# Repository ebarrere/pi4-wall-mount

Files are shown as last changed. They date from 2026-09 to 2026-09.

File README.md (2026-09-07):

# Raspberry Pi hanger

Use this to mount a Raspberry Pi 4 horizontally on the wall, assuming the Pi is mounted in [this case](https://www.printables.com/model/1240756-raspberry-pi-4-case-updated/files).

The mounting holes are sized and tapered for wood screws, but positioned to accomodate [Multiboard](https://thangs.com/designer/Keep%2520Making/3d-model/9x9%2520Multiboard%2520Core%2520Tile-977730).

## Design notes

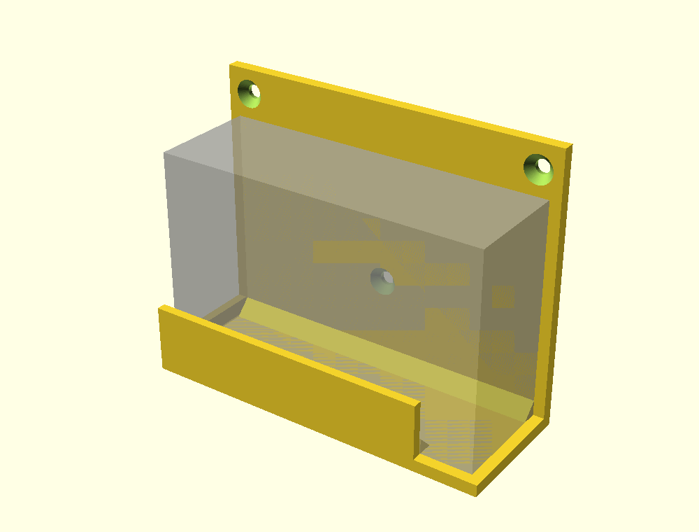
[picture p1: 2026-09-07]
pi4-wall-mount_iso.png

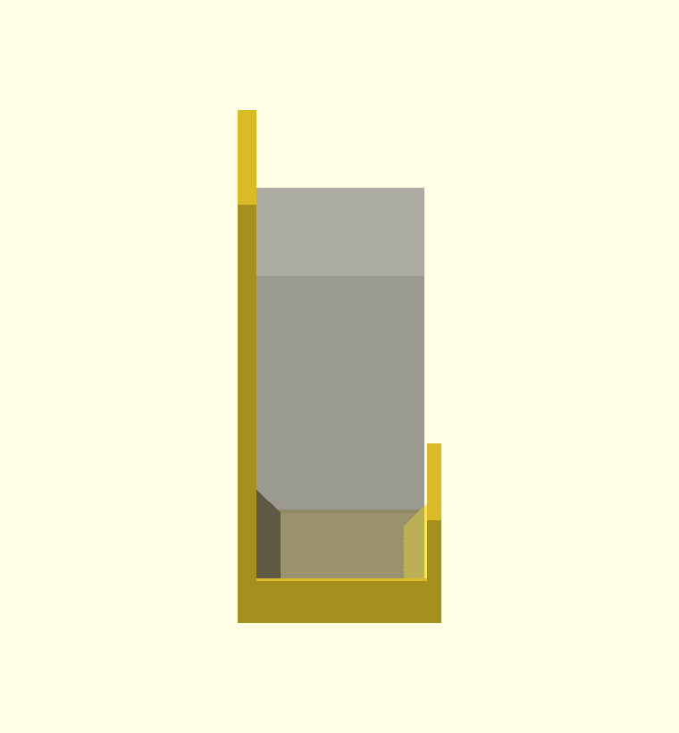
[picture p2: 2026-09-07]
pi4-wall-mount_side.png

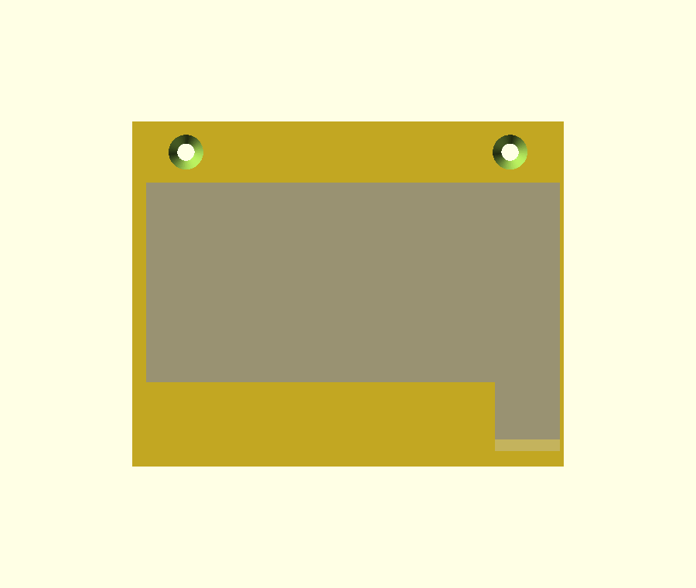
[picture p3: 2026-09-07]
pi4-wall-mount_front.png

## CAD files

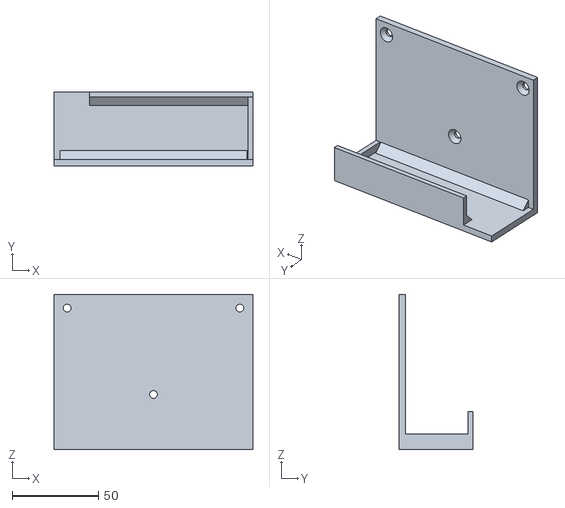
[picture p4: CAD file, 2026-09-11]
pi4-wall-mount.stl
115.2 x 43.1 x 90.0

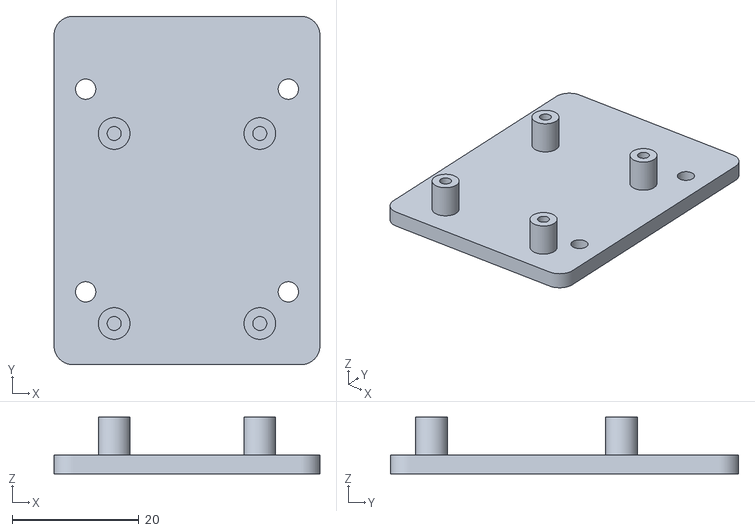
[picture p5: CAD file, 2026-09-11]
c790-pi-mount.stl
42.0 x 55.0 x 9.00

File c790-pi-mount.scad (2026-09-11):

// ============================================================================
// C790 (HDMI-to-CSI-2 capture, 30 x 45 mm PCB) -> Pi-case mounting tray
// Bolts to the case's 20 mm hole grid; stands the C790 off on 4 posts.
// Units: mm. Print flat (base on bed, posts up) -- no supports.
// ============================================================================

/* ========================= PARAMETERS ========================= */

// ---- C790 board ----
c790_w = 30;              // PCB width  (X)
c790_l = 45;              // PCB length (Y)
// Measured mounting-hole pattern (center-to-center). Board holes are 2.6 mm (M2.5).
c790_hole_dx = 23;        // hole spacing across the 30 mm WIDTH  (X)
c790_hole_dy = 30;        // hole spacing along  the 45 mm LENGTH (Y)
standoff_h   = 6;         // how high to lift the board off the base
standoff_od  = 5;         // post outer diameter (keeps clear of the fan holes)
board_screw_d = 2.2;      // hole in each post: 2.2 = self-tap M2.5; 2.7 = clearance for through-screw + nut
post_setback = 6;         // shift the posts (and board) toward a short edge (-Y); centered on the long edge. Flip sign for the other short edge.

// ---- Mount to the case-top FAN screw holes (4 holes in a square) ----
fan_pitch    = 32;        // fan hole spacing, on-center (40 mm fan = 32 mm; measure to confirm)
fan_screw_d  = 3.2;       // clearance for the fan screws (~M3)

// ---- Base plate ----
base_th     = 3;          // plate thickness
base_margin = 5;          // material around the widest feature
corner_r    = 3;          // corner radius
show_board_ghost = true;  // translucent PCB outline for visual check (not printed)

$fn = 64;
/* ============================================================== */


/* ------- derived geometry ------- */
hx = c790_hole_dx/2;                    // C790 hole X offset from center
hy = c790_hole_dy/2;                    // C790 hole Y offset from center
c790_holes = [[hx,hy],[-hx,hy],[hx,-hy],[-hx,-hy]];

// posts sit setback toward a short edge (-Y); no X offset keeps them centered on the long edge
post_holes = [ for (p = c790_holes) [p[0], p[1] - post_setback] ];

// fan mount holes: 4 in a square at fan_pitch on-center
fan_holes = [ for (sx=[-1,1], sy=[-1,1]) [sx*fan_pitch/2, sy*fan_pitch/2] ];

base_w = max(c790_w, fan_pitch) + 2*base_margin;
base_l = max(c790_l, fan_pitch) + 2*base_margin;


/* ------- helper modules ------- */
module rounded_square(w, l, r) {
    hull() for (sx=[-1,1], sy=[-1,1])
        translate([sx*(w/2-r), sy*(l/2-r)]) circle(r=r);
}


/* ------- the part ------- */
module tray() {
    difference() {
        union() {
            // base plate
            linear_extrude(base_th) rounded_square(base_w, base_l, corner_r);
            // C790 standoffs
            for (p = post_holes)
                translate([p[0], p[1], 0])
                    cylinder(d=standoff_od, h=base_th + standoff_h);
        }
        // fan-mount holes (through the base)
        for (p = fan_holes) translate([p[0], p[1], -0.5])
            cylinder(d=fan_screw_d, h=base_th + 1);
        // board screw holes (top-down into each post only)
        for (p = post_holes)
            translate([p[0], p[1], base_th])
                cylinder(d=board_screw_d, h=standoff_h + 1);
    }
}

tray();

// translucent ghost of the C790 sitting on the posts (visual only)
if (show_board_ghost)
    %translate([0, -post_setback, base_th + standoff_h])
        linear_extrude(1.2) square([c790_w, c790_l], center=true);

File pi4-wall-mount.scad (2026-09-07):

// ============================================================================
// Raspberry Pi 4 case -> wall-mount cradle (ikea-type shelf side wall)
// Mounted pose: case flat against the wall, power/HDMI edge UP. Held by a floor
// + short front lip + a side lip along the USB/Ethernet edge. Back plate screws
// to the shelf board (countersunk). Inside 45-deg fillets mate the case's
// bottom chamfers.
//
// Coords: X = horizontal (along wall), Y = out from wall, Z = up. Units: mm.
// The USB/Ethernet ("back") edge is the +X side; the case protrusion is on the
// far (-X) side, so the front lip is offset toward +X to clear it.
// Set usb_on_right=false to mirror everything to the other hand.
// ============================================================================

/* ===== CASE (measured, assembled, as mounted) ===== */
case_w = 108;    // horizontal width against the wall
case_h = 70;     // vertical height
case_d = 35.5;   // depth out from the wall
case_chamfer = 5;// case's 45-deg bottom-edge chamfer (measured); drives inside fillets
fit    = 0.6;    // clearance around the case

/* ===== BACK PLATE ===== */
plate_th   = 4;
top_margin = 16;   // strip above the case (top screws)

/* ===== CRADLE ===== */
floor_th     = 4;
front_lip_th = 3;
front_lip_h  = 18;
front_lip_w  = 91;   // < case_w, offset toward +X to clear the far-side protrusion
side_lip_th  = 3;    // lip along the USB/Ethernet (+X) edge
side_lip_h   = 5;    // its height above the floor

/* ===== WOOD SCREWS (countersunk; 1" #8) ===== */
screw_shank_d = 4.5;
head_d        = 9.0;
cs_angle      = 82;
// Hole layout on a 25mm lattice so it drops onto Multiboard (25mm tile pitch):
// two top holes 100mm apart, one low-center hole 50mm below -> all spacings x25.
screw_grid    = 25;
screw_top_x   = 50;    // top pair at +/- this (must be a multiple of screw_grid)
screw_low_dz  = 50;    // low-center hole this far below the top row (multiple of grid)

usb_on_right   = true;   // false = mirror to the other hand
show_case_ghost = true;
$fn = 64;

/* ===== derived ===== */
yc0 = plate_th;                 // case back (flush on plate)
yc1 = yc0 + case_d;             // case front
yfl0 = yc1 + fit;               // front lip inner
yfl1 = yfl0 + front_lip_th;     // front lip outer
plate_h = floor_th + case_h + top_margin;
xr = case_w/2 + fit + side_lip_th;          // +X edge (includes the side lip)
xl = -xr;                                   // symmetric plate -> even screw margins
fl_x1 = xr;                                 // +X end reaches out to meet the side lip
fl_x0 = case_w/2 - front_lip_w;             // far (-X) end
cs_depth = (head_d - screw_shank_d)/2 / tan(cs_angle/2);
screw_z_top = plate_h - top_margin/2;

module box(x0,x1,y0,y1,z0,z1) translate([x0,y0,z0]) cube([x1-x0, y1-y0, z1-z0]);

// 45-deg inside fillet along X (concave floor/wall corner), dir=+1 opens +Y
module fillet_x(x0,x1, yc,zc, size, dir)
    translate([x0,0,0]) rotate([90,0,90]) linear_extrude(x1-x0)
        polygon([[yc,zc],[yc+dir*size,zc],[yc,zc+size]]);

module cs_hole(x,z) translate([x,0,z]) rotate([-90,0,0]) {
    translate([0,0,-1]) cylinder(d=screw_shank_d, h=plate_th+2);
    translate([0,0,plate_th-cs_depth]) cylinder(d1=screw_shank_d, d2=head_d+0.4, h=cs_depth+0.2);
}

module bracket() {
    difference() {
        union() {
            box(xl, xr, 0, plate_th, 0, plate_h);                       // back plate
            box(xl, xr, plate_th, yfl1, 0, floor_th);                   // floor
            box(fl_x0, fl_x1, yfl0, yfl1, 0, floor_th + front_lip_h);   // front lip (offset +X)
            box(case_w/2 + fit, xr, yc0, yfl1, 0, floor_th + side_lip_h);// side lip (extends to meet the front lip)
            fillet_x(-case_w/2, case_w/2, yc0, floor_th, case_chamfer, +1); // back-bottom fillet
            fillet_x(fl_x0, fl_x1,        yfl0, floor_th, case_chamfer, -1); // front-bottom fillet (flush to front lip)
        }
        cs_hole(-screw_top_x, screw_z_top);
        cs_hole( screw_top_x, screw_z_top);
        cs_hole(0, screw_z_top - screw_low_dz);
    }
    if (show_case_ghost)
        %translate([-case_w/2, yc0, floor_th]) cube([case_w, case_d, case_h]);
}

if (usb_on_right) bracket();
else mirror([1,0,0]) bracket();

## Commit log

2026-09-07 Pi 4 wall-mount cradle: initial parametric prototype
    Back plate + bottom cradle (floor + short front lip), two countersunk wood-screw
    holes, measured case 108x70x35.5, built as a chamfered Y-Z cross-section.
    [pi4-wall-mount.scad]
2026-09-07 Inside fillets, back lip, 91mm front lip, 3rd screw
    - Replace outer bottom chamfers with inside 45-deg fillets that mate the case's
    own bottom chamfers (case_chamfer param) so it seats flush.
    - Front lip narrowed to 91mm to clear a case protrusion; add a full-width 5mm
    back lip so the case bottom sits in a shallow channel.
    - Add a low-center countersunk screw. Rebuilt box-based (varied-width lips).
    [pi4-wall-mount.scad]
2026-09-07 Relocate lip to the USB/Ethernet side edge; offset front lip
    - "back" lip was misplaced toward the wall; remove it and add a lip along the
    USB/Ethernet side edge (Y-Z plane, +X). Case now sits flush on the plate.
    - Offset the 91mm front lip toward the USB/Ethernet side so it clears the
    protrusion on the far (-X) side.
    - Box helper takes explicit X bounds (bracket is now asymmetric); add
    usb_on_right flag to mirror hands.
    [pi4-wall-mount.scad]
2026-09-07 Measured 5mm chamfer; extend front lip -X by side-lip thickness
    - case_chamfer 3 -> 5 (measured) so the inside fillets match.
    - Extend the front lip's far (-X) end by side_lip_th; its length no longer
    ignores the side lip.
    [pi4-wall-mount.scad]
2026-09-07 Extend front lip +X end to meet the side lip
    Reach the front lip's USB-side end out to the bracket edge so it joins the side
    lip, instead of extending the far end.
    [pi4-wall-mount.scad]
2026-09-07 Side lip meets front lip; screw holes on a 25mm Multiboard grid
    - Extend the side lip forward (yc1 -> yfl1) so it joins the front lip; closes
    the front-bottom gap.
    - Symmetric plate (xl = -xr) for even screw margins.
    - Screw holes on a 25mm lattice: top pair 100mm apart, low-center 50mm below and
    50mm inboard -> drops onto Multiboard (25mm tile pitch).
    [pi4-wall-mount.scad]
2026-09-07 Move front-bottom fillet flush to the front lip
    Anchor the front fillet at the front lip inner face (yfl0) instead of the case
    front (yc1), so it sits flush against the lip.
    [pi4-wall-mount.scad]
2026-09-11 Add c790 mount; track STL previews for GitHub render
    Un-ignore *.stl so GitHub shows a 3D preview; ignore sliced *.gcode.
    [c790-pi-mount.scad, c790-pi-mount.stl, pi4-wall-mount.stl]
